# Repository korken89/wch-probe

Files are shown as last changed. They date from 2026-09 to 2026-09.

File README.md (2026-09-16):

# wch-probe

KiCad hardware for a CH347F-based JTAG & SWD debug probe. USB-C on one end, a
10-pin 1.27 mm Cortex debug header on the other, plus a UART on the bottom-side
TX/RX/GND pads. The I/O voltage (VIO) tracks the target's VTref (valid range
1.8 V to 3.3 V), and defaults to 3.3 V when the target does not drive VTref.

<p align="center">
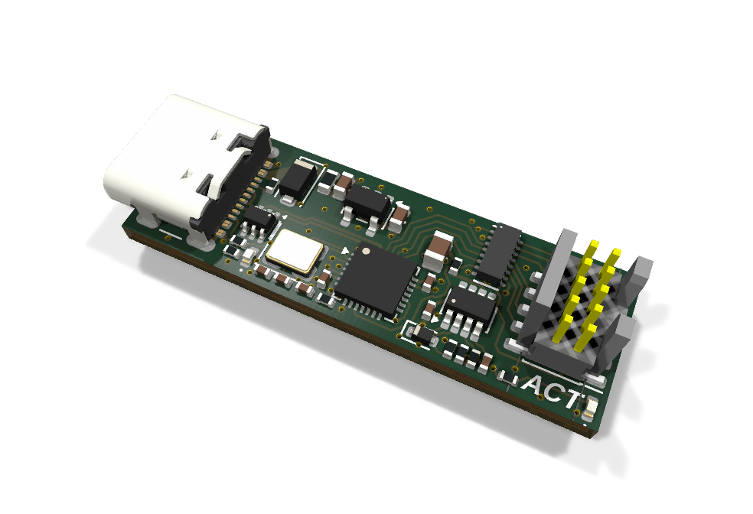
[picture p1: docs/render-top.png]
Board top
  
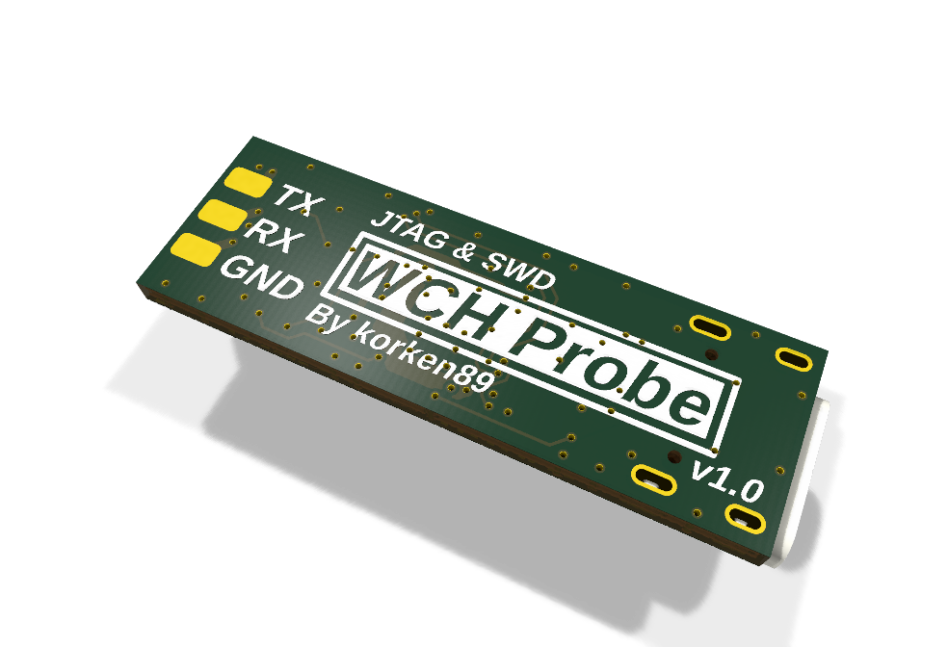
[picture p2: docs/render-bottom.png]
Board bottom
  
</p>

## Fabrication

The fabrication outputs (gerber zip, BOM, placement file, schematic PDF) for
each board revision are attached to the
[releases](https://github.com/korken89/wch-probe/releases). To generate them
locally, `make fab` writes the same set to `Fabrication/` and `make check`
runs ERC and DRC; both need KiCad 10's `kicad-cli`.

## Ordering

JLCPCB, 4 layers, 1.6 mm thick. Order options:

- Stackup: JLC04161H-7628 with impedance control (the USB pair is 90 ohm
  differential)
- Surface finish: HASL lead-free

## USB identity

Stock CH347s ship with a blank config and all enumerate with the same default serial.
Use [wch-cfg](https://github.com/korken89/wch-cfg) to write each board's USB identity
(serial number, product and manufacturer strings):

```sh
wch-cfg version --min 1.01 && wch-cfg write --init --random-serial --product wch-probe --manufacturer korken89
# replug the board (the chip reads the strings at power-on), then
wch-cfg verify --serial <the printed serial> --product wch-probe --manufacturer korken89
```

`write` prints the serial for the label on stdout once the OS has enumerated it.

## Gotchas

### Several probes behind one hub can fail to enumerate.

The CH347 declares its interrupt endpoints with 125/250 us polling, and the
host controller reserves that bandwidth at enumeration whether the endpoints
are used or not. After a few probes it will error with `can't set config #1,
error -28` ("Not enough bandwidth"). Work around it on Linux by treating
the `bInterval` values as milliseconds (will support 8x more probes - UART,
JTAG and SWD run on bulk endpoints and are unaffected):

```sh
echo '1a86:55de:l' | sudo tee /sys/module/usbcore/parameters/quirks
```

then replug the probes (quirks apply at enumeration). To make it permanent,
add `usbcore.quirks=1a86:55de:l` to the kernel command line. `dmesg` printing
`endpoint 0x85 has an invalid bInterval 1, changing to 4` for each probe
confirms the quirk is active.

## License

CERN-OHL-P-2.0, see [LICENSE](LICENSE).

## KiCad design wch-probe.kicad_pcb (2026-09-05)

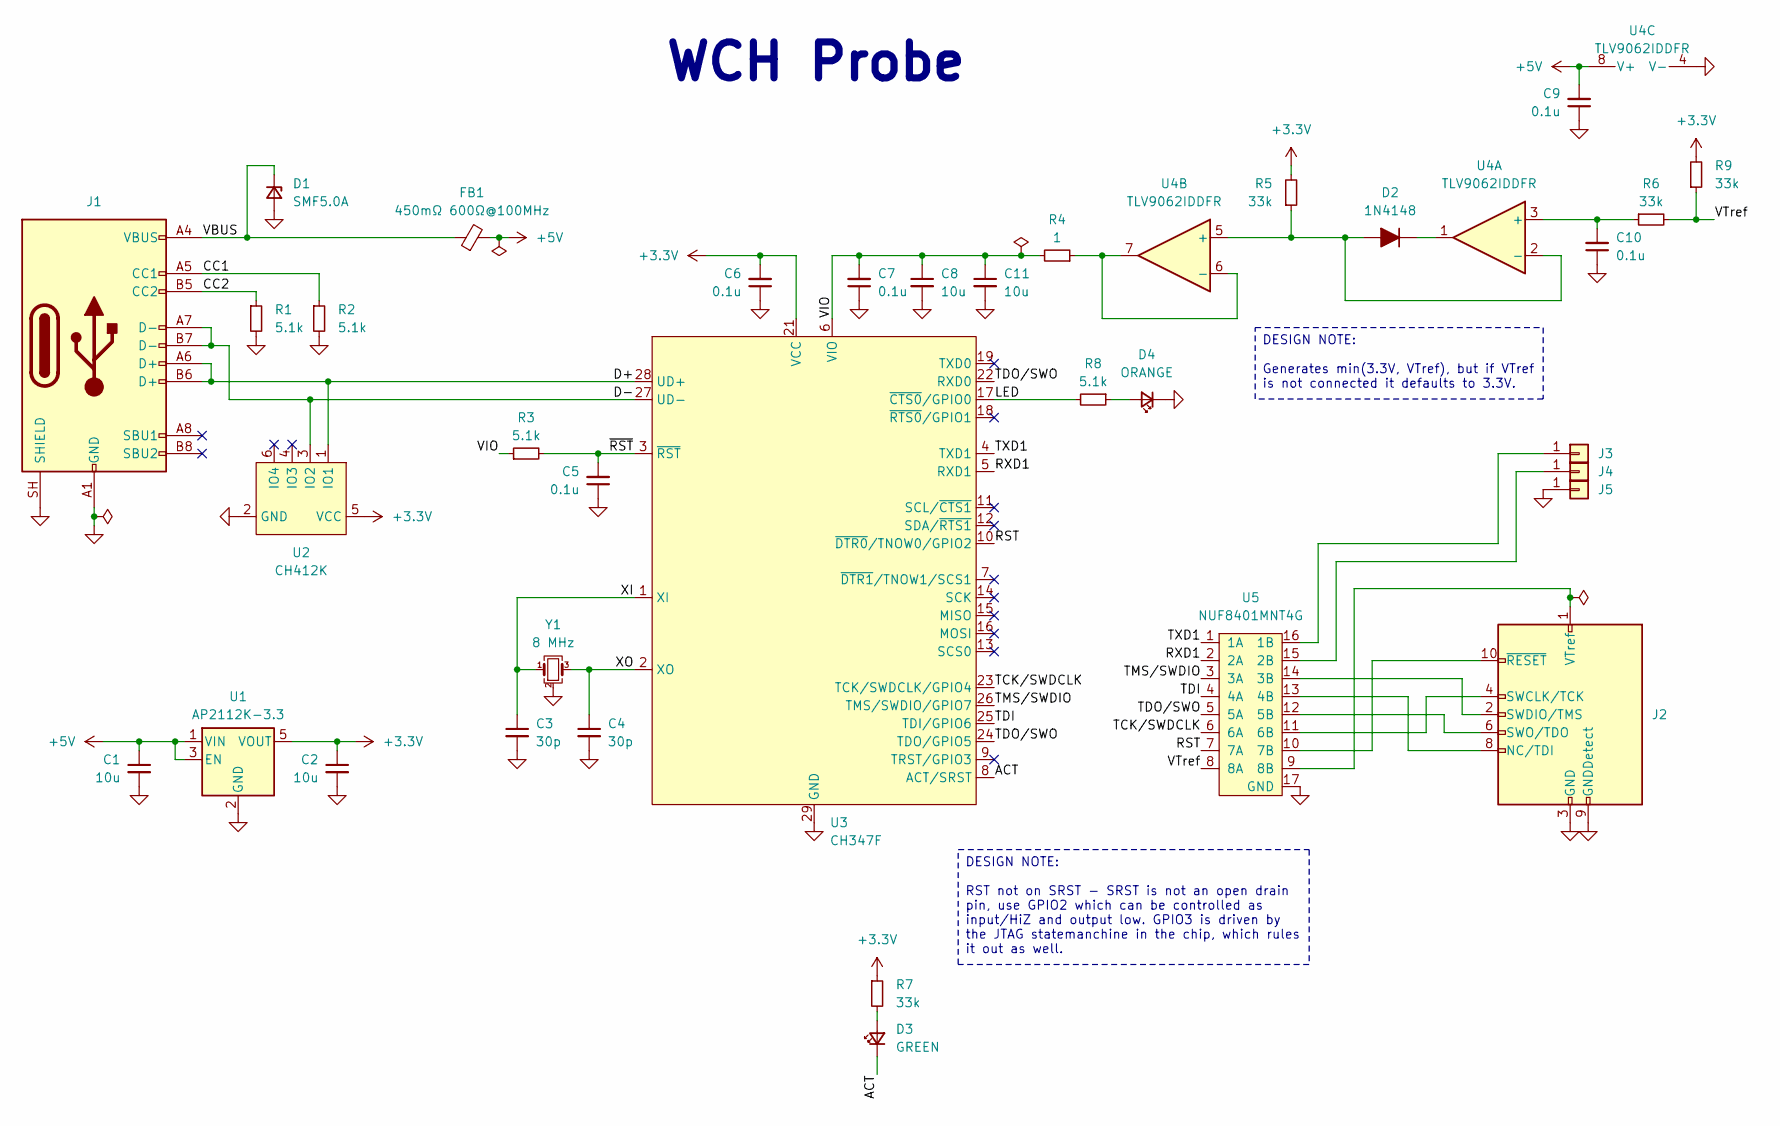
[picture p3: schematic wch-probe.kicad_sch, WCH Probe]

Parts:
C1, C2, C8, C11: 10u; C_0603; LCSC C96446
C3, C4: 30p; C_0402; LCSC C1570
C5, C6, C7, C9, C10: 0.1u; C_0402; LCSC C1525
D1: SMF5.0A; D_SOD-123F; LCSC C151296
D2: 1N4148; D_SOD-523; LCSC C83482
D3: GREEN; LED_0402_1005Metric; LCSC C5123485
D4: ORANGE; LED_0402_1005Metric; LCSC C965791
FB1: 450mΩ 600Ω@100MHz; R_0603; LCSC C1002
J1: USB_C_Receptacle_USB2.0_14P; USB_C_Receptacle_GCT_USB4105-xx-A_16P_TopMnt_Horizontal; LCSC C165948
J2: Conn_ARM_JTAG_SWD_10; PinHeader_2x05_FTSH-105-01-L-DV-K; LCSC C5155080
J3, J4, J5: Conn_01x01; pad_1.5x2.5mm
R1, R2, R3, R8: 5.1k; R_0402; LCSC C25905
R4: 1; R_0402; LCSC C25086
R5, R6, R7, R9: 33k; R_0402; LCSC C25779
U1: AP2112K-3.3; SOT-23-5; LCSC C23380830
U2: CH412K; SOT-363_SC-70-6; LCSC C89184
U3: CH347F; WQFN-28-1EP_4x4mm_P0.4mm_EP2.7x2.7mm; LCSC C18221627
U4: TLV9062IDDFR; SOT-23-8; LCSC C2867884
U5: NUF8401MNT4G; DFN-16-1EP_1.6x4mm_P0.5mm; LCSC C895158
Y1: 8 MHz; Crystal_SMD_3225-4Pin_3.2x2.5mm; LCSC C5563850

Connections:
+3.3V: C2.1, C6.2, R5.2, R7.1, R9.2, U1.5 (VOUT), U2.5 (VCC), U3.21 (VCC)
+5V: C1.1, C9.2, FB1.2, U1.1 (VIN), U1.3 (EN), U4.8 (V+)
/ACT: D3.1 (K), U3.8 (ACT/SRST)
/CC1: J1.A5 (CC1), R2.1
/CC2: J1.B5 (CC2), R1.1
/D+: J1.A6 (D+), J1.B6 (D+), U2.1 (IO1), U3.28 (UD+)
/D-: J1.A7 (D-), J1.B7 (D-), U2.3 (IO2), U3.27 (UD-)
/LED: R8.2, U3.17 (~CTS0/GPIO0)
/RST: U3.10 (~DTR0/TNOW0/GPIO2), U5.7 (7A)
/RXD1: U3.5 (RXD1), U5.2 (2A)
/TCK/SWDCLK: U3.23 (TCK/SWDCLK/GPIO4), U5.6 (6A)
/TDI: U3.25 (TDI/GPIO6), U5.4 (4A)
/TDO/SWO: U3.22 (RXD0), U3.24 (TDO/GPIO5), U5.5 (5A)
/TMS/SWDIO: U3.26 (TMS/SWDIO/GPIO7), U5.3 (3A)
/TXD1: U3.4 (TXD1), U5.1 (1A)
/VBUS: D1.1 (K), FB1.1, J1.A4 (VBUS), J1.A9 (VBUS), J1.B4 (VBUS), J1.B9 (VBUS)
/VIO: C7.2, C8.1, C11.1, R3.1, R4.2, U3.6 (VIO)
/VTref: R6.2, R9.1, U5.8 (8A)
/XI: C3.1, U3.1 (XI), Y1.1
/XO: C4.1, U3.2 (XO), Y1.3
/~RST: C5.2, R3.2, U3.3 (~RST)
GND: C1.2, C2.2, C3.2, C4.2, C5.1, C6.1, C7.1, C8.2, C9.1, C10.1, C11.2, D1.2 (A), D4.1 (K), J1.A1 (GND), J1.A12 (GND), J1.B1 (GND), J1.B12 (GND), J1.SH (SHIELD), J2.3 (GND), J2.5 (GND), J2.9 (GNDDetect), J5.1 (Pin_1_1), R1.2, R2.2, U1.2 (GND), U2.2 (GND), U3.20 (GND), U3.29 (GND), U4.4 (V-), U5.17 (GND), Y1.2 (G), Y1.4 (G)
unnamed: D2.2 (A), R5.1, U4.2 (-), U4.5 (+)
unnamed: D2.1 (K), U4.1
unnamed: D3.2 (A), R7.2
unnamed: D4.2 (A), R8.1
unnamed: J2.8 (NC/TDI), U5.13 (4B)
unnamed: J2.4 (SWCLK/TCK), U5.11 (6B)
unnamed: J2.2 (SWDIO/TMS), U5.14 (3B)
unnamed: J2.6 (SWO/TDO), U5.12 (5B)
unnamed: J2.1 (VTref), U5.9 (8B)
unnamed: J2.10 (~RESET), U5.10 (7B)
unnamed: J3.1 (Pin_1_1), U5.16 (1B)
unnamed: J4.1 (Pin_1_1), U5.15 (2B)
unnamed: C10.2, R6.1, U4.3 (+)
unnamed: R4.1, U4.6 (-), U4.7

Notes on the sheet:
WCH Probe
DESIGN NOTE: RST not on SRST - SRST is not an open drain pin, use GPIO2 which can be controlled as input/HiZ and output low. GPIO3 is driven by the JTAG statemanchine in the chip, which rules it out as well.
DESIGN NOTE: Generates min(3.3V, VTref), but if VTref is not connected it defaults to 3.3V.

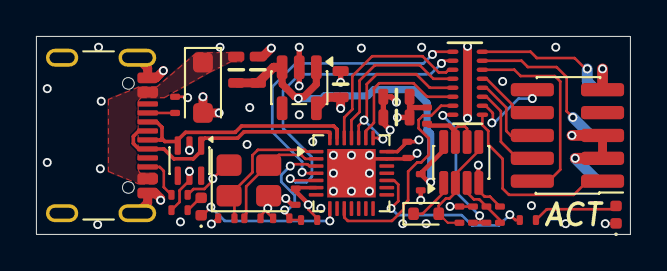
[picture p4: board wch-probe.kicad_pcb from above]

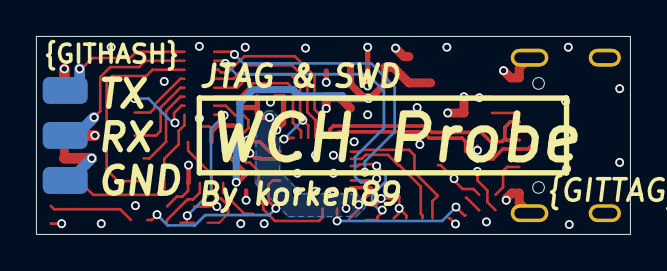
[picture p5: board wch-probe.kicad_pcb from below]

Board: 4 copper layers, 33.0 x 11.0 mm, 36 parts (3 on the bottom side), 36 nets.
